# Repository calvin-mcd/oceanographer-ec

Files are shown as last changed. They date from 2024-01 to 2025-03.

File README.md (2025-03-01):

# oceanographer-ec

This is a EC (topre) pcb for Hedgey's [oceanographer](https://geekhack.org/index.php?topic=114413.0) keyboard. The pcb supports both a 625U spacebar and a split 275U, 225U spacebar configuration, an Oled and rotary encoder.
Each layout requires its own respective plate. The plate files can be found in the production folder.

## Layout

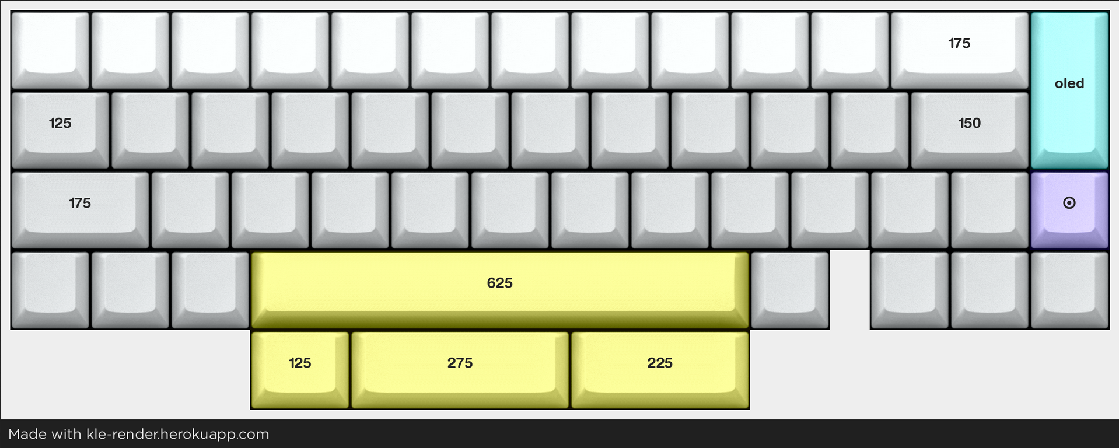
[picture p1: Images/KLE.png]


[Link](http://www.keyboard-layout-editor.com/#/gists/06cea779d76d209e57f1c44d0aa36c97)

## Firmware

The basic EC firmware is ready to go and the source code is provided for tweaking any settings.

## Plates & Hardware

Plate files are available for OEM (original and deskey housings).

Furthermore, you will need 25x 10mm M2 screws and M2 nuts to assemble the pcb. 

## Disclaimer

This PCB has been fully tested and is confirmed to work. However, no-one involved in this project is responsible for any usage issues that may arise. Order at your own risk. Feel free to edit, modify and otherwise utilise these files.

## License

Shield: 

This work is licensed under a  
[Creative Commons Attribution-NonCommercial-ShareAlike 4.0 International License](http://creativecommons.org/licenses/by-nc-sa/4.0/).



## Credits

This is a commission for darth_foster.

big thanks to petejohanson for feedback and help!

Furthermore, many thanks for feedback, help, references go to Sporkus, Cipulot\#8455 & matthewdias\#2671.

Any questions, contact Calvin0563 on Discord.

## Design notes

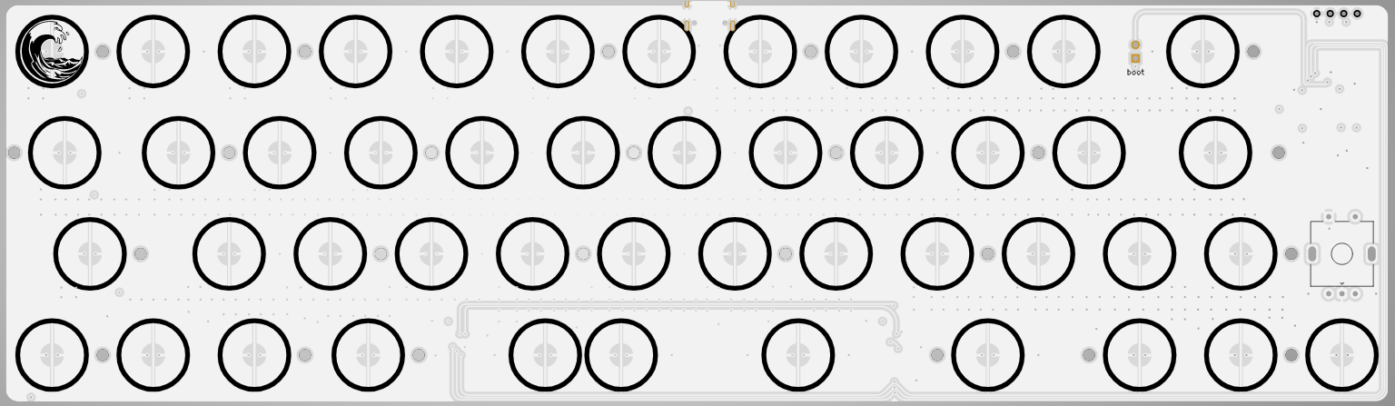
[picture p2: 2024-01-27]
Images/top.png

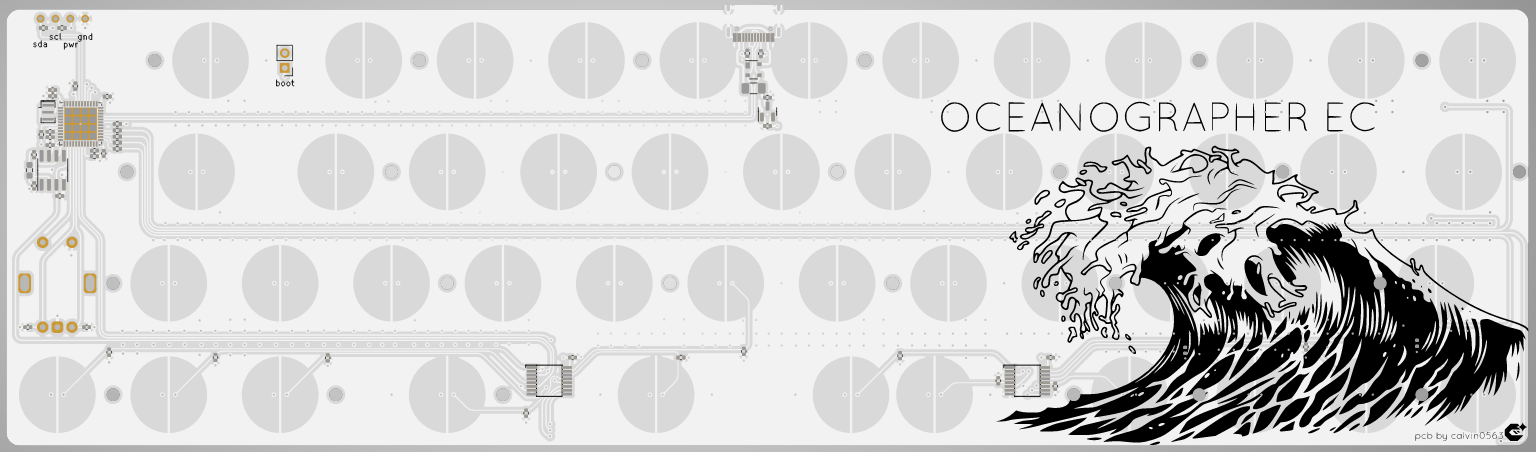
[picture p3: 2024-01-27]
Images/bottom.png

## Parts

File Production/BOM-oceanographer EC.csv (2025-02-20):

Comment | Designator | Footprint | LCSC | Quantity
1k | R25 | R_0402_1005Metric | C11702 | 1
STM32F401CBUx | U1 | QFN-48-1EP_7x7mm_P0.5mm_EP5.6x5.6mm | C118825 | 1
OPA350 | U6 | SOIC-8_3.9x4.9mm_P1.27mm | C13388 | 1
220p | C14 | C_0402_1005Metric | C1530 | 1
4.7u | C1 | C_0402_1005Metric | C23733 | 1
100 | R2,R3,R4,R5 | R_0402_1005Metric | C25076 | 4
100k | R1,R11,R12,R13,R14,R15,R18,R19,R20,R21,R22,R23,R24,R26 | R_0402_1005Metric | C25741 | 14
10k | R10,R7,R8 | R_0402_1005Metric | C25744 | 3
4.7k | R16,R17 | R_0402_1005Metric | C25900 | 2
5.1k | R6,R9 | R_0402_1005Metric | C25905 | 2
PRTR5V0U2X | D1 | SOT-143 | C2827688 | 1
TYPEC-304YSSW-ACP16 | USB1 | HRO-TYPE-C-31-M-12 | C2840392 | 1
100n | C10,C11,C12,C13,C15,C2,C3,C4,C5,C6 | C_0402_1005Metric | C307331 | 10
1u | C7,C8,C9 | C_0402_1005Metric | C52923 | 3
XC6206PxxxMR | U2 | SOT-23 | C5446 | 1
74HC4051 | U3,U5 | TSSOP16 | C5645 | 2
500mA | F_USBC1 | Fuse_1206_3216Metric | C70076 | 1
8 MHz | Y1 | Resonator_SMD_Murata_CSTxExxV-3Pin_3.0x1.1mm | C907975 | 1

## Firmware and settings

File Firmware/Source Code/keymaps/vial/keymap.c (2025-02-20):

/* SPDX-License-Identifier: GPL-2.0-or-later */

#include QMK_KEYBOARD_H

const uint16_t PROGMEM keymaps[][MATRIX_ROWS][MATRIX_COLS] = {

[0] = LAYOUT_big_bar( \
  KC_ESC,   KC_Q,   KC_W,   KC_E,   KC_R,   KC_T,   KC_Y,   KC_U,   KC_I,     KC_O,    KC_P,     KC_BSPC,  \
  KC_TAB,   KC_A,   KC_S,   KC_D,   KC_F,   KC_G,   KC_H,   KC_J,   KC_K,     KC_L,    KC_SLASH, KC_ENTER, \
  KC_LSFT,  KC_Z,   KC_X,   KC_C,   KC_V,   KC_B,   KC_N,   KC_M,   KC_COMMA, KC_DOT,  KC_RSFT,  KC_UP, \
  KC_LCTL, KC_LGUI, KC_LALT,                KC_SPC,                           KC_RALT,  KC_LEFT, KC_DOWN, KC_RIGHT, \
  KC_NO \
),
[1] = LAYOUT_big_bar( \
  KC_TRNS, KC_TRNS, KC_TRNS, KC_TRNS, KC_TRNS, KC_TRNS, KC_TRNS, KC_TRNS, KC_TRNS, KC_TRNS, KC_TRNS, KC_TRNS, \
  KC_TRNS, KC_TRNS, KC_TRNS, KC_TRNS, KC_TRNS, KC_TRNS, KC_TRNS, KC_TRNS, KC_TRNS, KC_TRNS, KC_TRNS, KC_TRNS, \
  KC_TRNS, KC_TRNS, KC_TRNS, KC_TRNS, KC_TRNS, KC_TRNS, KC_TRNS, KC_TRNS, KC_TRNS, KC_TRNS, KC_TRNS, KC_TRNS, \
  KC_TRNS, KC_TRNS, KC_TRNS,                   KC_TRNS,                            KC_TRNS, KC_TRNS, KC_TRNS, KC_TRNS, \
  KC_NO \
),
[2] = LAYOUT_big_bar( \
  KC_TRNS, KC_TRNS, KC_TRNS, KC_TRNS, KC_TRNS, KC_TRNS, KC_TRNS, KC_TRNS, KC_TRNS, KC_TRNS, KC_TRNS, KC_TRNS, \
  KC_TRNS, KC_TRNS, KC_TRNS, KC_TRNS, KC_TRNS, KC_TRNS, KC_TRNS, KC_TRNS, KC_TRNS, KC_TRNS, KC_TRNS, KC_TRNS, \
  KC_TRNS, KC_TRNS, KC_TRNS, KC_TRNS, KC_TRNS, KC_TRNS, KC_TRNS, KC_TRNS, KC_TRNS, KC_TRNS, KC_TRNS, KC_TRNS, \
  KC_TRNS, KC_TRNS, KC_TRNS,                   KC_TRNS,                            KC_TRNS, KC_TRNS, KC_TRNS, KC_TRNS, \
  KC_NO \
),
[3] = LAYOUT_big_bar( \
  KC_TRNS, KC_TRNS, KC_TRNS, KC_TRNS, KC_TRNS, KC_TRNS, KC_TRNS, KC_TRNS, KC_TRNS, KC_TRNS, KC_TRNS, KC_TRNS, \
  KC_TRNS, KC_TRNS, KC_TRNS, KC_TRNS, KC_TRNS, KC_TRNS, KC_TRNS, KC_TRNS, KC_TRNS, KC_TRNS, KC_TRNS, KC_TRNS, \
  KC_TRNS, KC_TRNS, KC_TRNS, KC_TRNS, KC_TRNS, KC_TRNS, KC_TRNS, KC_TRNS, KC_TRNS, KC_TRNS, KC_TRNS, KC_TRNS, \
  KC_TRNS, KC_TRNS, KC_TRNS,                   KC_TRNS,                            KC_TRNS, KC_TRNS, KC_TRNS, KC_TRNS, \
  KC_NO \
)

};

/* Encoder */
#ifdef ENCODER_MAP_ENABLE
const uint16_t PROGMEM encoder_map[][NUM_ENCODERS][NUM_DIRECTIONS] = {
    [0] = { ENCODER_CCW_CW(KC_VOLD, KC_VOLU) },
    [1] = { ENCODER_CCW_CW(KC_NO, KC_NO) },
    [2] = { ENCODER_CCW_CW(KC_NO, KC_NO) },
    [3] = { ENCODER_CCW_CW(KC_NO, KC_NO) }
};
#endif

/* OLED */

#ifdef OLED_ENABLE

static void print_status_narrow(void) {
	// Create OLED content
    oled_advance_page(true);
    oled_write_P(PSTR("Ocean EC"), false);
    oled_advance_page(true);

    // Print current layer
    oled_write_P(PSTR("Layer"), false);
    switch (get_highest_layer(layer_state)) {
        case 0:
            oled_write_P(PSTR("-Base\n"), false);
            break;
        case 1:
            oled_write_P(PSTR("Lyr 1\n"), false);
            break;
        case 2:
            oled_write_P(PSTR("Lyr 2\n"), false);
            break;
        case 3:
            oled_write_P(PSTR("Lyr 3\n"), false);
            break;
        default:
            oled_write_P(PSTR("Undef"), false);
    }
	
	// Display capslock

        // Host Keyboard LED Status
    led_t led_state = host_keyboard_led_state();
    oled_write_P(led_state.num_lock ? PSTR("Num ") : PSTR("    "), false);
    oled_write_P(led_state.caps_lock ? PSTR("Caps ") : PSTR("    "), false);
    oled_write_P(led_state.scroll_lock ? PSTR("Scrl ") : PSTR("    "), false);

}

bool oled_task_user(void) {
    print_status_narrow();
	return false;
}

#endif

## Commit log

2024-01-04 removed one of the superflous plate projects
    [plate split 2u.kicad_pcb, plate split.kicad_pcb]
2024-01-09 clean up
    [analog.kicad_sch, ec matrix.kicad_sch, mounting holes.kicad_sch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]
2024-01-19 update project
    [oceanographer EC-B_Cu.gbr, oceanographer EC-B_Mask.gbr, oceanographer EC-B_Paste.gbr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]
2024-01-27 redesign after missing switch
    [BOM-oceanographer EC.csv, ec matrix.kicad_sch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]
2024-02-23 fresh gerbers
    [oceanographer EC-B_Cu.gbr, oceanographer EC-B_Mask.gbr, oceanographer EC-B_Paste.gbr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]
2024-03-17 led firmware wip
    [BOM-oceanographer EC.csv]
2024-03-30 pcb & plate revisions
    [plate 625u OEM-B_Cu.gbr, plate 625u OEM-B_Mask.gbr, plate 625u OEM-B_Paste.gbr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]
2025-02-20 poroduction files
    [BOM-oceanographer EC.csv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]
2025-05-03 Update oceanographer EC.kicad_prl
